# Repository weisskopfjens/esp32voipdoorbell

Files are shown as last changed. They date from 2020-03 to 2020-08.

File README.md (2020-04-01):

# ESP32voipdoorbell
A voip based door bell / phone realized with ESP32 and s2i mems + s2i dac

**It is still under development.**

Working features:
* Connect to a SIP server ( fritzbox router )
* Initate a call ( SIP/SDP protocol )
* 3 seperate buttons. Each initiate a call to a diffrent phonenumber.
* A two way voice transmission between the doorphone and the called party. (RTP protocol, G.711 alaw codec )
* Web based configuration. Parameters and wifi credentials.
* Web based firmware update.

Planned features:
* Sitch a connected relais with a MFV tone.
* WS2812b LEDs for lightning the door bell lables and for giving an optical feedback.
* A wellcome message for visitors.

Used hardware:
* ESP32 dev board
* i2s MEMS mic type INMP441
* MAX98357 I2S audio amplifier
* 3x WS2812b LEDs

Requirements:
* ConfigManager@>=1.5.2
* ArduinoJson@>=5.13.4
* clickButton@2012.08.29
* NTP@1.3.1
* WS2812FX@1.2.3
* Adafruit NeoPixel@1.3.5

[Project homepage](https://jensweisskopf.de/wp/esp-32-als-voip-tuersprechstelle/)

## default PINOUT for ESP32voipdoorbell

|ESP32 GPIO | Connected to | notes |
|---|---|---|
|4 | Button 1 | second pin to gnd |
|2 | Button 2 | second pin to gnd |
|15 | Button 3 | second pin to gnd |
|I2S Amplifier| | |
|14 | BCLK | |
|12 | LRC | |
|27 | DIN | |
|I2S | | |
|26 | BCKL SCK | |
|25 | LRCL WS | |
|33 | DOUT SD | |
| | | |

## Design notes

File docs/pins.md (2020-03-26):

## default PINOUT for ESP32voipdoorbell

|ESP32 GPIO | Connected to | notes |
|---|---|---|
|4 | Button 1 | second pin to gnd |
|2 | Button 2 | second pin to gnd |
|15 | Button 3 | second pin to gnd |
|I2S Amplifier| | |
|14 | BCLK | |
|27 | LRC | |
|12 | DIN | |
|I2S | | |
|33 | BCKL SCK | |
|32 | LRCL WS | |
|35 | DOUT SD | |
| | | |

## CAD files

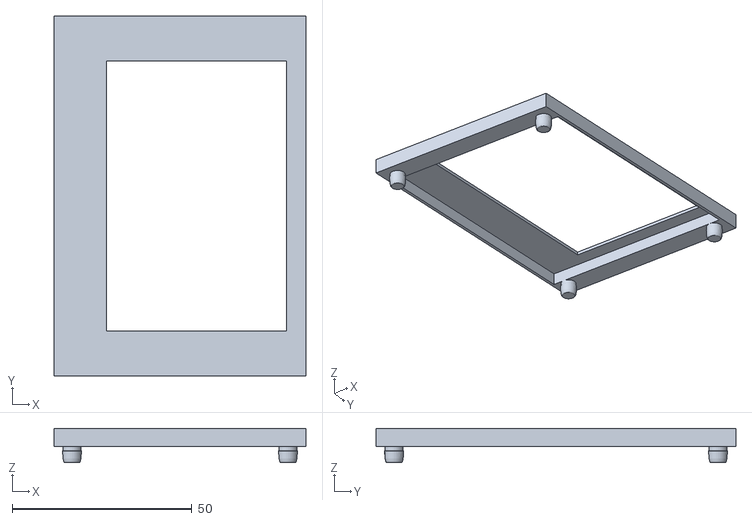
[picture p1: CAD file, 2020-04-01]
3dmodels/frame.stl
70.0 x 100.0 x 9.50

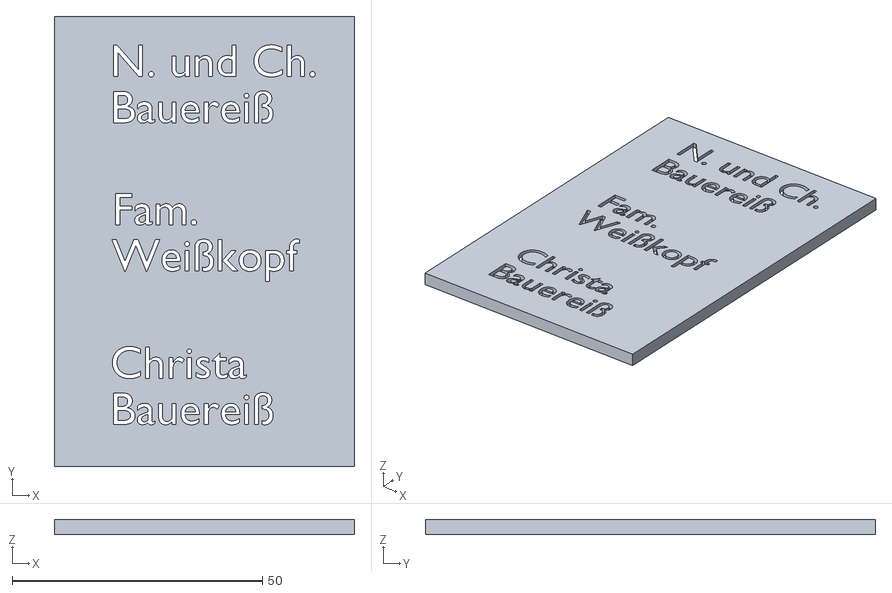
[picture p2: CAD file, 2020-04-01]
3dmodels/klingelschilder.stl
60.0 x 90.0 x 3.00

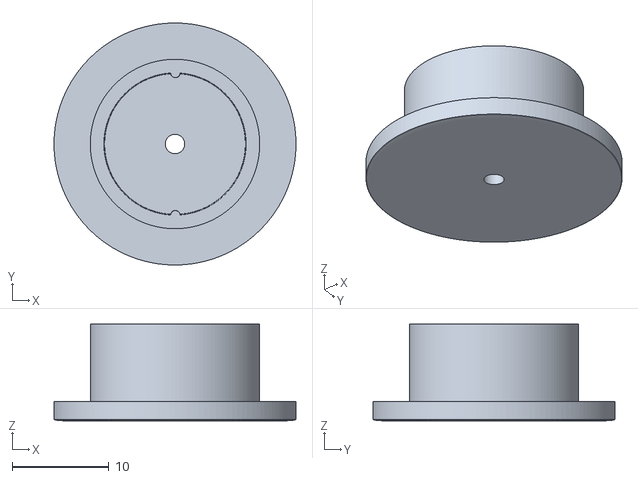
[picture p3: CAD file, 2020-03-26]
3dmodels/mic_holder_1.stl
25.0 x 25.0 x 10.0

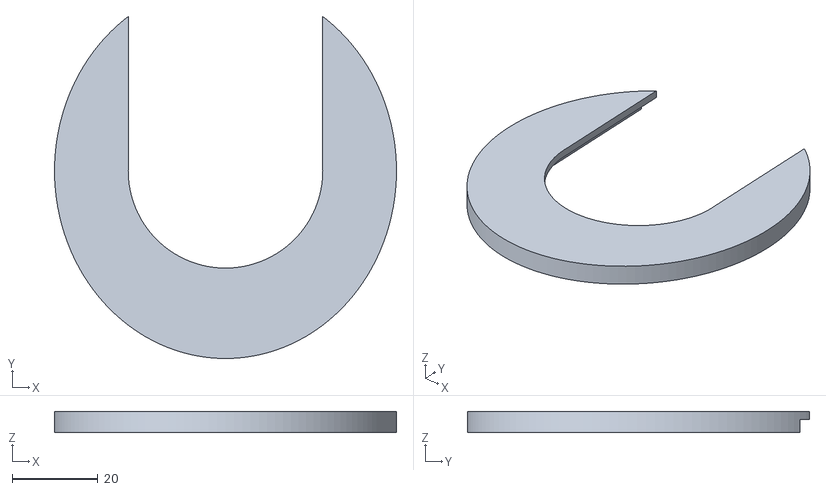
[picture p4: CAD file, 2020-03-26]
3dmodels/speaker_holder_1.stl
80.0 x 80.0 x 5.00

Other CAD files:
3dmodels/frame.blend
3dmodels/klingelschilder.blend
3dmodels/klingelschilderV2.blend
3dmodels/lable.blend
3dmodels/mic_holder_1.blend
3dmodels/speaker_holder_1.blend

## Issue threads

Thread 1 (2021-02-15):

Is it working ok?

createcandle, 2021-02-15:
I found your project on Github and was curious: is the project working ok? If so, what hardware would you recommend? I have a `[TTGO Camera with mic](https://www.tinytronics.nl/shop/en/communication/wi-fi/lilygo-ttgo-t-camera-mic-esp32-fisheye)` ESP32 module with built-in MEMS microphone. Perhaps that could work?

weisskopfjens, 2021-02-15:
Hello. Yes. For me it works. I use it in our 3 family house for a couple of months, as door bell. The quality of the voice connection is really poor. But it can be understand. I think it can be fixed, but i actually has no time for further research. Maybe someone other can do this. I think your cam modul should be work, but i think there will be performance problems if you want to use the voip connection and at the same time stream a video. I haven't try this yet. I use a simple esp32dev board. Perhaps, in the next weeks, i extend the documentation with some pictures and maybe an video. Furthermore i must update the code on github. I do some changes because of an stability issue. Now the doorbell reboots every night. This, and with a new high quality power adapter, the doorbell working stable. Sorry for my poor english. ;-)

createcandle, 2021-02-15:
Thanks. It sounds very recognisable :-)

indotronic, 2021-03-04:
i am working, but how to answer call? have code?

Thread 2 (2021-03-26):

vs code errors building projects

raulfash, 2021-03-26:
Hello great job, it mean you can read my mind.

I just will adapt this project to my owm pourposes.

By the way only want to get some experience whit platformio and then do adaptations to my spects.

When try build in VStudio code i get a lot of warnings.

`PLATFORM: Espressif 32 (1.12.4) > Espressif ESP32 Dev Module
HARDWARE: ESP32 240MHz, 320KB RAM, 4MB Flash
DEBUG: Current (esp-prog) External (esp-prog, iot-bus-jtag, jlink, minimodule, olimex-arm-usb-ocd, olimex-arm-usb-ocd-h, olimex-arm-usb-tiny-h, olimex-jtag-tiny, tumpa)
PACKAGES:
 - framework-arduinoespressif32 3.10004.210126 (1.0.4)
 - tool-esptoolpy 1.20600.0 (2.6.0)
 - toolchain-xtensa32 2.50200.97 (5.2.0)
LDF: Library Dependency Finder -> http://bit.ly/configure-pio-ldf
LDF Modes: Finder ~ chain, Compatibility ~ soft
ValueError: Invalid simple block '2012.08.29':
  File "C:\Users\FaSh\.platformio\penv\Lib\site-packages\platformio\builder\main.py", line 177:
    env.SConscript("$BUILD_SCRIPT")
  File "C:\Users\FaSh\.platformio\packages\tool-scons\scons-local-4.1.0\SCons\Script\SConscript.py", line 591:
    return _SConscript(self.fs, *files, **subst_kw)
  File "C:\Users\FaSh\.platformio\packages\tool-scons\scons-local-4.1.0\SCons\Script\SConscript.py", line 280:
    exec(compile(scriptdata, scriptname, 'exec'), call_stack[-1].globals)
  File "C:\Users\FaSh\.platformio\platforms\espressif32@1.12.4\builder\main.py", line 223:
    target_elf = env.BuildProgram()
  File "C:\Users\FaSh\.platformio\packages\tool-scons\scons-local-4.1.0\SCons\Util.py", line 658:
    return self.method(*nargs, **kwargs)
  File "C:\Users\FaSh\.platformio\penv\Lib\site-packages\platformio\builder\tools\platformio.py", line 62:
    env.ProcessProjectDeps()
  File "C:\Users\FaSh\.platformio\packages\tool-scons\scons-local-4.1.0\SCons\Util.py", line 658:
    return self.method(*nargs, **kwargs)
  File "C:\Users\FaSh\.platformio\penv\Lib\site-packages\platformio\builder\tools\platformio.py", line 140:
    project_lib_builder = env.ConfigureProjectLibBuilder()
  File "C:\Users\FaSh\.platformio\packages\tool-scons\scons-local-4.1.0\SCons\Util.py", line 658:
    return self.method(*nargs, **kwargs)
  File "C:\Users\FaSh\.platformio\penv\Lib\site-packages\platformio\builder\tools\piolib.py", line 1062:
    project.install_dependencies()
  File "C:\Users\FaSh\.platformio\penv\Lib\site-packages\platformio\builder\tools\piolib.py", line 886:
    if lm.get_package(spec):
  File "c:\users\fash\.platformio\penv\lib\site-packages\platformio\package\manager\base.py", line 234:
    spec = self.ensure_spec(spec)
  File "c:\users\fash\.platformio\penv\lib\site-packages\platformio\package\manager\base.py", line 102:
    return spec if isinstance(spec, PackageSpec) else PackageSpec(spec)
  File "c:\users\fash\.platformio\penv\lib\site-packages\platformio\package\meta.py", line 124:
    self._parse(self.raw)
  File "c:\users\fash\.platformio\penv\lib\site-packages\platformio\package\meta.py", line 227:
    raw = parser(raw)
  File "c:\users\fash\.platformio\penv\lib\site-packages\platformio\package\meta.py", line 250:
    self.requirements = tokens[1].strip()
  File "c:\users\fash\.platformio\penv\lib\site-packages\platformio\package\meta.py", line 167:
    else semantic_version.SimpleSpec(str(value))
  File "c:\users\fash\.platformio\penv\lib\site-packages\semantic_version\base.py", line 618:
    self.clause = self._parse_to_clause(expression)
  File "c:\users\fash\.platformio\penv\lib\site-packages\semantic_version\base.py", line 1014:
    return cls.Parser.parse(expression)
  File "c:\users\fash\.platformio\penv\lib\site-packages\semantic_version\base.py", line 1034:
    raise ValueError("Invalid simple block %r" % block)
================================== [FAILED] Took 1.31 seconds ==================================
The terminal process "C:\Users\FaSh\.platformio\penv\Scripts\platformio.exe 'debug', '--environment', 'esp32dev'" terminated with exit code: 1.
`

Thanks a lot

raulfash, 2021-03-31:
I answer to myself.
Some compilation bugs fixed.

Installed libraries in the user folder platformio.

One error due to FS windows that confuses uppercase with lowercase "Math.h", "math.h".
It is solved with lib_ignore = time in platformio.ini
Static error in Dusk2Dawn library, Static is eliminated in the header of the functions with cpp error.

Now compile, and it remains to receive the esp32 to upload.

Now my dismemberment begins.
I do not need a screen or LEDs or the solar time function.
Also I will try that the system connects to the sip only when it is pressed.

Thanks for your work, I really like it.

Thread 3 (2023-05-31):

SPIFFS: mount failed

agoetz1984, 2023-05-31:
Hello,

after compiling and uploading the firmware the SPIFFS gets following issue:

E (111501) SPIFFS: mount failed, -10025

Thank you!

Andy

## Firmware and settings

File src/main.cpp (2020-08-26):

#include <Arduino.h>
#include <SPI.h>
#include <WiFi.h>
#include <WebServer.h>
#include "HTTPUpdateServer.h"
#include <WiFiUdp.h>
#include "NTP.h"
#include "ConfigManager.h"
#include "voipphone.h"
#include "ClickButton.h"
#include <Adafruit_NeoPixel.h>
#include <Dusk2Dawn.h>
#include <TimeLib.h>
#include "pages.h"

#define WS2812PIN 32
#define NUMPIXELS 3
Adafruit_NeoPixel pixels(NUMPIXELS, WS2812PIN, NEO_GRB + NEO_KHZ400);

#define mDNSUpdate(c)  do {} while(0)
using WebServerClass = WebServer;
using HTTPUpdateServerClass = HTTPUpdateServer;

HTTPUpdateServer httpUpdate;
VOIPPhone doorphone;
bool doorphonerunning = false;

ClickButton button1(4, LOW, CLICKBTN_PULLUP);
ClickButton button2(2, LOW, CLICKBTN_PULLUP);
ClickButton button3(15, LOW, CLICKBTN_PULLUP);

bool islighton=false;
bool isbusy=false;

//
// Config manager...
//

const char *settingsHTML = (char *)"/settings.html";
const char *stylesCSS = (char *)"/styles.css";
const char *mainJS = (char *)"/main.js";

struct Config {
  char device_name[32];
  char telnr_1[32];
  char telnr_2[32];
  char telnr_3[32];
  char sip_user[32];
  char sip_pass[32];
  char sip_ip[32];
  uint8_t mic_gain;
  uint8_t amp_gain;
  int tz_dst;
  int tz_std;
  float lat;
  float lon;
  uint8_t light_r;
  uint8_t light_g;
  uint8_t light_b;
  uint8_t ring_r;
  uint8_t ring_g;
  uint8_t ring_b;
  bool echocompensation;
  uint8_t echodamping;
  uint echothreshold;
} config;

struct Metadata {
  int8_t version;
} meta;

ConfigManager configManager;

WiFiUDP wifiUdp;
NTP ntp(wifiUdp);

void APCallback(WebServer *server) {
    server->on("/styles.css", HTTPMethod::HTTP_GET, [server](){
        //configManager.streamFile(stylesCSS, mimeCSS);
        server->send_P(200,mimeCSS,CSS_styles);
    });

    DebugPrintln(F("AP Mode Enabled. You can call other functions that should run after a mode is enabled ... "));
}


void APICallback(WebServer *server) {
  server->on("/disconnect", HTTPMethod::HTTP_GET, [server](){
    configManager.clearWifiSettings(false);
  });

  server->on("/settings.html", HTTPMethod::HTTP_GET, [server](){
    //configManager.streamFile(settingsHTML, mimeHTML);
    server->send_P(200,mimeHTML,HTML_settings);
  });

  // NOTE: css/js can be embedded in a single page HTML
  server->on("/styles.css", HTTPMethod::HTTP_GET, [server](){
    //configManager.streamFile(stylesCSS, mimeCSS);
    server->send_P(200,mimeCSS,CSS_styles);
  });

  server->on("/main.js", HTTPMethod::HTTP_GET, [server](){
    //configManager.streamFile(mainJS, mimeJS);
    server->send_P(200,mimeJS,JS_main);
  });
  
  server->on("/datetime", HTTPMethod::HTTP_GET, [server](){
    server->send(200, "text/plain", ntp.formattedTime("%d.%m.%Y %X"));
  });
  
  server->on("/debug", HTTPMethod::HTTP_GET, [server](){
    String output = String(ntp.formattedTime("%d.%m.%Y %X"))+"</br>";
    Dusk2Dawn location = Dusk2Dawn(config.lat, config.lon, config.tz_std/60);
    int sr_min = location.sunrise( ntp.year(), ntp.month(), ntp.day(), ntp.isDST() );
    int ss_min = location.sunset( ntp.year(), ntp.month(), ntp.day(), ntp.isDST() );
    int min = ntp.hours()*60+ntp.minutes();
    output += "Now:"+String(min)+"</br>";
    output += "Sunrise:"+String(sr_min)+"</br>";
    output += "Sunset:"+String(ss_min)+"</br>";
    output += "LED0:"+String(pixels.getPixelColor(0));
    output += "LED1:"+String(pixels.getPixelColor(1));
    output += "LED2:"+String(pixels.getPixelColor(2));
    server->send(200, mimeHTML, output);
  });

  server->on("/restart", HTTPMethod::HTTP_GET, [server](){
    ESP.restart();
    server->send(200, "text/plain", "restarting...");
  });

  server->on("/dial1", HTTPMethod::HTTP_GET, [server](){
    doorphone.dial(config.telnr_1,config.device_name);
    server->send(200, "text/plain", "ok");
  });

  server->on("/dial2", HTTPMethod::HTTP_GET, [server](){
    doorphone.dial(config.telnr_2,config.device_name);
    server->send(200, "text/plain", "ok");
  });

  server->on("/dial3", HTTPMethod::HTTP_GET, [server](){
    doorphone.dial(config.telnr_3,config.device_name);
    server->send(200, "text/plain", "ok");
  });

  httpUpdate.setup(server);
}

void setup() {
  Serial.begin(115200);
  Serial.println();
  Serial.println("Startup...");
  pixels.begin();
  pixels.setPixelColor(0, pixels.Color(255, 0, 0));
  pixels.setPixelColor(1, pixels.Color(0, 255, 0));
  pixels.setPixelColor(2, pixels.Color(0, 0, 255));
  pixels.show();

  pinMode(4,INPUT_PULLUP);
  pinMode(2,INPUT_PULLUP);
  pinMode(15,INPUT_PULLUP);

  strcpy(config.device_name,"\0");
  strcpy(config.telnr_1,"\0");
  strcpy(config.telnr_2,"\0");
  strcpy(config.telnr_3,"\0");
  strcpy(config.sip_ip,"\0");
  strcpy(config.sip_user,"\0");
  strcpy(config.sip_pass,"\0");

  meta.version = 1;
  config.tz_dst = 120;
  config.tz_std = 60;
  // Setup config manager
  configManager.setAPName("voipdoorbell");
  configManager.setAPFilename("/index.html");
  // Settings variables 
  configManager.addParameter("device_name", config.device_name, 32);
  configManager.addParameter("telnr_1", config.telnr_1, 32);
  configManager.addParameter("telnr_2", config.telnr_2, 32);
  configManager.addParameter("telnr_3", config.telnr_3, 32);
  configManager.addParameter("sip_ip", config.sip_ip, 32);
  configManager.addParameter("sip_user", config.sip_user, 32);
  configManager.addParameter("sip_pass", config.sip_pass, 32);
  configManager.addParameter("mic_gain", &config.mic_gain);
  configManager.addParameter("amp_gain", &config.amp_gain);
  configManager.addParameter("tz_dst", &config.tz_dst);
  configManager.addParameter("tz_std", &config.tz_std);
  configManager.addParameter("lat", &config.lat);
  configManager.addParameter("lon", &config.lon);
  configManager.addParameter("light_r", &config.light_r);
  configManager.addParameter("light_g", &config.light_g);
  configManager.addParameter("light_b", &config.light_b);
  configManager.addParameter("ring_r", &config.ring_r);
  configManager.addParameter("ring_g", &config.ring_g);
  configManager.addParameter("ring_b", &config.ring_b);
  configManager.addParameter("echocompensation", &config.echocompensation);
  configManager.addParameter("echodamping", &config.echodamping);
  configManager.addParameter("echothreshold", &config.echothreshold);
  // Meta Settings
  configManager.addParameter("version", &meta.version, get);
  // Init Callbacks
  configManager.setAPCallback(APCallback);
  configManager.setAPICallback(APICallback);
  configManager.begin(config);

  ntp.ruleDST("CEST", Last, Sun, Mar, 2, config.tz_dst); // last sunday in march 2:00, timezone +120min (+1 GMT + 1h summertime offset)
  ntp.ruleSTD("CET", Last, Sun, Oct, 3, config.tz_std); // last sunday in october 3:00, timezone +60min (+1 GMT)
  ntp.begin();
}

void loop() {
  if (WiFi.status() == WL_CONNECTED ) {
    ntp.update();
    if(strlen(config.sip_ip)<7) {
      //Serial.println("Configuration fault.");
    } else {
      if( !doorphonerunning ) {
        Serial.print("Online. Starting sip modul...");
        if(int result = doorphone.begin(config.sip_ip,config.sip_user,config.sip_pass)==VOIPPHONE_OK) {
          doorphone.setAmpGain(config.amp_gain);
          doorphone.setMicGain(config.mic_gain);
          doorphone.setEchoCompensation(config.echocompensation,config.echothreshold,config.echodamping);
          Serial.println("[OK]");
        } else {
          Serial.print("[ERROR CODE:"+(String)result+"]");
        }
        doorphonerunning = true;
        /*pixels.setPixelColor(0, pixels.Color(255, 255, 255));
        pixels.setPixelColor(1, pixels.Color(255, 255, 255));
        pixels.setPixelColor(2, pixels.Color(255, 255, 255));
        pixels.show();
        pixels.clear();
        pixels.show();
        pixels.setPixelColor(0, pixels.Color(0, 0, 0));
        pixels.setPixelColor(1, pixels.Color(0, 0, 0));
        pixels.setPixelColor(2, pixels.Color(0, 0, 0));*/
        pixels.clear();
        pixels.show();
      }
      button1.Update();
      button2.Update();
      button3.Update();
      if(button1.clicks==1) {
        Serial.println("Button1 pressed. Dialing...");
        doorphone.dial(config.telnr_1,config.device_name);
        pixels.setPixelColor(2, pixels.Color(config.ring_r, config.ring_g, config.ring_b));
        pixels.show();
        isbusy = true;
      } else if(button2.clicks==1) {
        Serial.println("Button2 pressed. Dialing...");
        doorphone.dial(config.telnr_2,config.device_name);
        pixels.setPixelColor(1, pixels.Color(config.ring_r, config.ring_g, config.ring_b));
        pixels.show();
        isbusy = true;
      } else if(button3.clicks==1) {
        Serial.println("Button3 pressed. Dialing...");
        doorphone.dial(config.telnr_3,config.device_name);
        pixels.setPixelColor(0, pixels.Color(config.ring_r, config.ring_g, config.ring_b));
        pixels.show();
        isbusy = true;
      }
    }
  }
  
  configManager.loop();
  doorphone.loop();

  // hangup
  if(isbusy && !doorphone.isBusy()) {
    isbusy = false;
    pixels.clear();
    pixels.show();
    islighton = false;
  }

  Dusk2Dawn location = Dusk2Dawn(config.lat, config.lon, config.tz_std/60);
  int sr_min = location.sunrise( ntp.year(), ntp.month(), ntp.day(), ntp.isDST() );
  int ss_min = location.sunset( ntp.year(), ntp.month(), ntp.day(), ntp.isDST() );
  int min = ntp.hours()*60+ntp.minutes();
  if(min > ss_min || min < sr_min) { // lights on
    if (!islighton) {
      islighton = true;
      pixels.setPixelColor(0, pixels.Color(config.light_r, config.light_g, config.light_b));
      pixels.setPixelColor(1, pixels.Color(config.light_r, config.light_g, config.light_b));
      pixels.setPixelColor(2, pixels.Color(config.light_r, config.light_g, config.light_b));
      pixels.show();
    }
  } else { // lights off
    if (islighton) {
      islighton = false;
      pixels.clear();
      pixels.setPixelColor(0, pixels.Color(0, 0, 0));
      pixels.setPixelColor(1, pixels.Color(0, 0, 0));
      pixels.setPixelColor(2, pixels.Color(0, 0, 0));
      pixels.show();
    }
  }
}

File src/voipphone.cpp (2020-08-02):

#include"voipphone.h"

//bool DEBUG_MODE = false;
Sip *VOIPPhone::sip = NULL;
WiFiUDP VOIPPhone::rtpudp = WiFiUDP();
uint8_t VOIPPhone::amp_gain = AMP_GAIN;
uint8_t VOIPPhone::mic_gain = MIC_GAIN;
bool VOIPPhone::echocompensation = false;
uint8_t VOIPPhone::echodamping = 1;

VOIPPhone::VOIPPhone() {
  
}

int VOIPPhone::begin(const char *sipip,const char *sipuser,const char *sippasswd) {
  
  strcpy(myip,WiFi.localIP().toString().c_str());
  int connOK = rtpudp.begin(1234);
  if (connOK == 0) {
    DebugPrintln("rtpudp (port:1234) could not get socket");
    return VOIPPHONE_ERROR_RTPSOCKET;
  } else {
    DebugPrintln("rtpudp listen on (port:1234)");
  }
  DebugPrint("Init SIP...");
  sip = new Sip(caSipOut, sizeof(caSipOut));
  sip->Init(sipip, sipport , myip, sipport, sipuser, sippasswd); // 15 seconds
  DebugPrintln("[OK]");
  // i2s devices
  int result = initi2smic();
  if(result!=VOIPPHONE_OK) {
    return result;
  }
  result = initi2samp();
  if(result!=VOIPPHONE_OK) {
    return result;
  }
  return VOIPPHONE_OK;
}

//
// Dialing
//

void VOIPPhone::dial(const char *number,const char *id) {
  DebugPrintln("Dialing");
  i2s_start(I2S_PORT1);
  DebugPrintln("I2SPORT1 start");
  rx_streamisrunning = true;
  sip->Dial(number, id, 15);
  DebugPrintln("sip->Dial executed");
}

//
// Loop
//

void VOIPPhone::loop(void) {
  if(WiFi.status() == WL_CONNECTED) {
    handleIncommingRTP();
    handleOutgoingRTP();
    sip->HandleUdpPacket();
  }
}

void VOIPPhone::setMicGain(uint8_t gain) {
  mic_gain = gain;
}

void VOIPPhone::setAmpGain(uint8_t gain) {
  amp_gain = gain;
}

bool VOIPPhone::isBusy(void) {
  return sip->IsBusy();
}


//
// Initialize i2s amplifier
//

int VOIPPhone::initi2samp() {
  esp_err_t err;
  // The I2S config as per the example
  const i2s_config_t i2s_config = {
      .mode = i2s_mode_t(I2S_MODE_MASTER | I2S_MODE_TX), // Receive, not transfer
      .sample_rate = SAMPLE_RATE,                         // 16KHz
      .bits_per_sample = I2S_BITS_PER_SAMPLE_16BIT, // could only get it to work with 32bits
      .channel_format = I2S_CHANNEL_FMT_ONLY_LEFT, // although the SEL config should be left, it seems to transmit on right
      .communication_format = i2s_comm_format_t(I2S_COMM_FORMAT_I2S | I2S_COMM_FORMAT_I2S_MSB),
      .intr_alloc_flags = ESP_INTR_FLAG_LEVEL1,     // Interrupt level 1
      .dma_buf_count = 16,                           // number of buffers
      .dma_buf_len = 60,                    // 8 samples per buffer (minimum)
      .use_apll = false
  };
  // The pin config as per the setup
  const i2s_pin_config_t pin_config = {
      .bck_io_num = 14,   // BCLK
      .ws_io_num = 12,    // LRC
      .data_out_num = 27, // DOUT -> DIN
      .data_in_num = -1   // not used
  };
  // Configuring the I2S driver and pins.
  // This function must be called before any I2S driver read/write operations.
  DebugPrintln("Init i2s amp...");
  err = i2s_driver_install(I2S_PORT1, &i2s_config, 0, NULL);
  if (err != ESP_OK) {
    Serial.printf("Failed installing driver: %d\n", err);
    return VOIPPHONE_ERROR_AMP_I2S_DRIVER;
  }
  err = i2s_set_pin(I2S_PORT1, &pin_config);
  if (err != ESP_OK) {
    Serial.printf("Failed setting pin: %d\n", err);
    return VOIPPHONE_ERROR_AMP_PIN;
  }
  DebugPrintln("I2S driver installed.");
  return VOIPPHONE_OK;
}

//
// Initialize i2s microphone
//

int VOIPPhone::initi2smic() {
  esp_err_t err;
  // The I2S config as per the example
  const i2s_config_t i2s_config = {
      .mode = i2s_mode_t(I2S_MODE_MASTER | I2S_MODE_RX), // Receive, not transfer
      .sample_rate = SAMPLE_RATE,                         // 16KHz
      .bits_per_sample = I2S_BITS_PER_SAMPLE_32BIT, // could only get it to work with 32bits
      .channel_format = I2S_CHANNEL_FMT_ONLY_LEFT, // although the SEL config should be left, it seems to transmit on right
      .communication_format = i2s_comm_format_t(I2S_COMM_FORMAT_I2S | I2S_COMM_FORMAT_I2S_MSB),
      .intr_alloc_flags = ESP_INTR_FLAG_LEVEL1,     // Interrupt level 1
      .dma_buf_count = 4,                           // number of buffers
      .dma_buf_len = 8                              // 8 samples per buffer (minimum)
  };
  // The pin config as per the setup
  const i2s_pin_config_t pin_config = {
      .bck_io_num = 26,   // BCKL SCK
      .ws_io_num = 25,    // LRCL WS
      .data_out_num = -1, // not used (only for speakers)
      .data_in_num = 33   // DOUT SD
  };
  // Configuring the I2S driver and pins.
  // This pfunction must be called before any I2S driver read/write operations.
  DebugPrintln("Init i2s mems...");
  err = i2s_driver_install(I2S_PORT0, &i2s_config, 0, NULL);
  if (err != ESP_OK) {
    Serial.printf("Failed installing driver: %d\n", err);
    return VOIPPHONE_ERROR_MIC_I2S_DRIVER;
  }
  err = i2s_set_pin(I2S_PORT0, &pin_config);
  if (err != ESP_OK) {
    Serial.printf("Failed setting pin: %d\n", err);
    return VOIPPHONE_ERROR_MIC_PIN;
  }
  DebugPrintln("I2S driver installed.");
  return VOIPPHONE_OK;
}

//
// Read from microphone
//

esp_err_t VOIPPhone::readFromMic(void *dest,size_t size,size_t *bytes_read) {
  return i2s_read(I2S_PORT0,dest,size,bytes_read,portMAX_DELAY); // no timeout
}

esp_err_t VOIPPhone::writeToAmp(const void *src,size_t size, size_t *bytes_written) {
  return i2s_write(I2S_PORT1,src,size,bytes_written,portMAX_DELAY);
}

//
// Send RTP packet every 20ms
//
void VOIPPhone::tx_rtp(){
  uint8_t temp[160];
  static uint16_t sequenceNumber = 0;
  const uint32_t ssrc = 3124150;
  static uint32_t timestamp = 0;
  RTPPacket txRTPpkg;
  uint8_t packetBuffer[255];

  for(int i=0;i<160;i++) {
    //8192 13bit
    //16777216 u24bit
    SAMPLE_T sample = 0;
    size_t num_bytes_read;
    //i2s_read(I2S_PORT0,&sample,sizeof(SAMPLE_T),&num_bytes_read,portMAX_DELAY); // no timeout
    readFromMic(&sample,sizeof(SAMPLE_T),&num_bytes_read);
    if (num_bytes_read > 0) {
      if(echocompensation) {
        temp[i] = ALaw_Encode(MIC_CONVERT(sample)*mic_gain/echodamping);
      } else {
        temp[i] = ALaw_Encode(MIC_CONVERT(sample)*mic_gain);
      }
      
    }
  }
  if(sequenceNumber==0) {
    timestamp = 0;
  }
  txRTPpkg = RTPPacket(temp, sequenceNumber++, ssrc, timestamp+=160,8,160);
  int length = txRTPpkg.serialize(packetBuffer);
  IPAddress tempip;
  tempip.fromString(sip->GetSIPServerIP()); 
  int beginOK = rtpudp.beginPacket(tempip, atoi(sip->audioport) );
  if (beginOK == 0) {
    //rtpudp.stop();
  } else {
    rtpudp.write(packetBuffer,length);
    //int endOK = rtpudp.endPacket();
    rtpudp.endPacket();
  }
}
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

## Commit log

2020-03-26 Add models for 3d printer
    [mic_holder_1.blend, mic_holder_1.stl, speaker_holder_1.blend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]
2020-04-01 New labels for 3d printing
    [frame.blend, frame.stl, klingelschilder.blend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]
2020-04-14 Add parameters for time and leds
2020-08-26 Fix leds with wrong color.
    [main.cpp]
